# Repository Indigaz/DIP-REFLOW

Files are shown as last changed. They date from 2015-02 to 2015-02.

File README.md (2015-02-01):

# DIP-REFLOW
An all through-hole, Arduino powered, reflow oven controller.

Have you ever wondered why most toaster oven reflow controllers require a shield on a development board,
or the controller has a number of surface mounted components on the PCB?  I did too and I didn't want to
sacrifice a development board, that I frequently use and tear apart, into a long-term installation such
as a reflow controller.

This reflow controller is based on RocketScream's Arduino shield based reflow controller, however, this is
a fully hand solderable, all through-hole implementaion.  It makes use of a MAX31855 breakout board
available from Adafruit (http://www.adafruit.com/product/269) to read the K-type thermocouple.

The Arduino code has been pieced together from several sources to add the features and to get the 
functionality that I was looking for. 

**I still need to finish up a Bill-of-Materials list and cleanup the code somewhat.  Boards will be available on
OSHPark for a quick purchase or you can send off the .BRD file to your fab shop of choice.  I'll also look
at rendering a quality PDF file for those that might want to try and hand craft the PCB at home.  Note, this is
a two sided board.**

I will have this project also tracked at http://hackaday.io for more information such as assembly photos.

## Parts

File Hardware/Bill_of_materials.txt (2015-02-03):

DIP_REFLOW's initial Bill-of-materials:

Qty (1) ATMEGA328PDIP  (with or without Arduino bootloader.  ICSP worked into board.)
Qty (1) MAX31855 Breakout board (http://www.adafruit.com/product/269)
Qty (1) K-type thermocouple (Found on Adafruit, eBay or many other sites.)
Qty (1) 16x4 HD44780 Character LCD Display Module (Various sites)
Qty (1) 16 Mhz Crystal oscillator (Various sites)
Qty (1) 10k Ohm potentiometer (Various sites)
Qty (2) LED's (One RED and on GREEN) (Various sites)
Qty (3) Push button momentary switch (Various sites)
Qty (3) 2N3904 Transistor
Qty (2) 22pF Ceramic caps
Qty (3) .1uF Ceramic caps
Qty (3) 10k Ohm resistors
Qty (2) 330 Ohm resistors
Qty (4) Small 2 screw terminals
Qty (1) 3X2 ICSP header
Qty (1) 6 pin female header for MAX31855 breakout
Qty (1) 6 pin male or female header depending on your FTDI breakout
Qty (1) 7805 in TO220 size

This is just a quick draft to get information up and available.  I will later create a proper BOM
with part numbers and source location.

If anyone notices a problem, please alert me!  I'm pretty sure I've forgotten something.  Thanks!

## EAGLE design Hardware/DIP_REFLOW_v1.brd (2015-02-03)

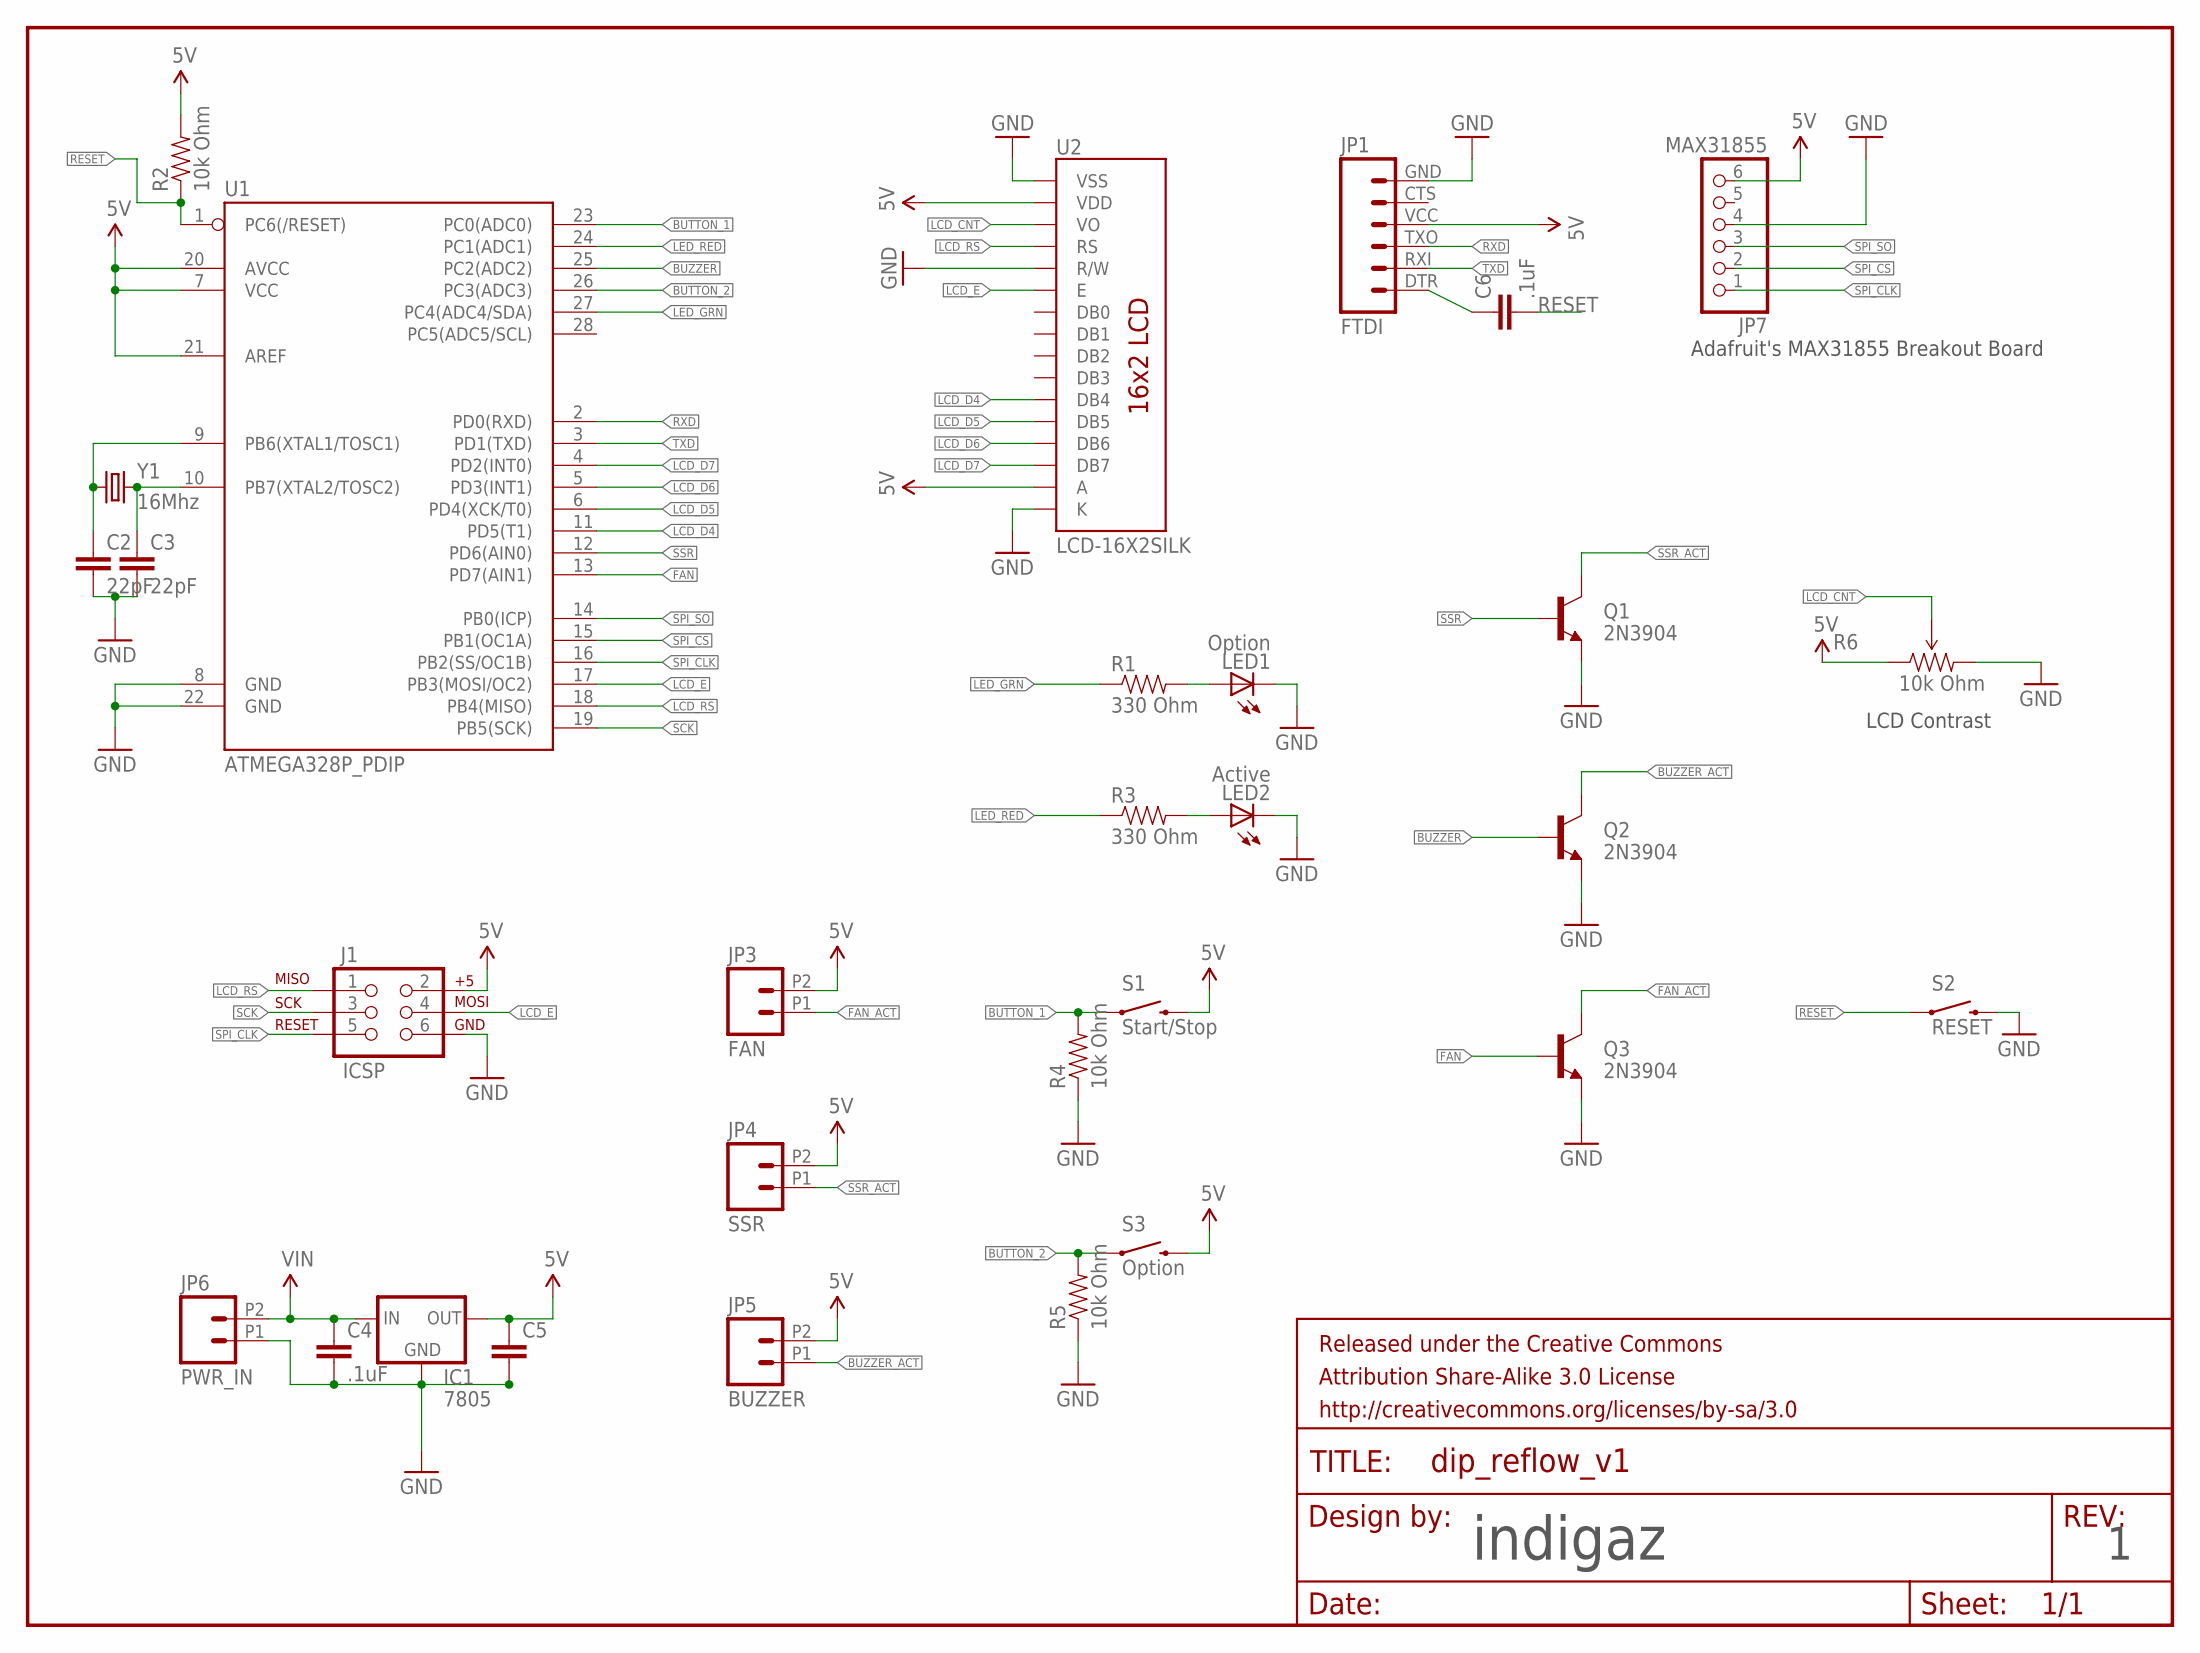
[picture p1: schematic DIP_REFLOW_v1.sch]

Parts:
C2, C3: 22pF; CAP-PTH-5MM
C4, C6: .1uF; CAP-PTH-5MM
C5: CAPPTH1; CAP-PTH-5MM
FRAME1: FRAME-LETTER; CREATIVE_COMMONS
IC1: 7805; TO-220-ALT
J1: ICSP; 2X3
JP1: FTDI; FTDI_BASIC
JP3: FAN; 1X02_2.54_SCREWTERM
JP4: SSR; 1X02_2.54_SCREWTERM
JP5: BUZZER; 1X02_2.54_SCREWTERM
JP6: PWR_IN; 1X02_2.54_SCREWTERM
JP7: MAX31855; 1X06
LED1: Option; LED5MM
LED2: Active; LED5MM
Q1, Q2, Q3: 2N3904; TO-92-AMMO
R1, R3: 330 Ohm; AXIAL-0.4
R2, R4, R5: 10k Ohm; AXIAL-0.4
R6: 10k Ohm; 3386U
S1: Start/Stop; TACTILE-PTH
S2: RESET; TACTILE-PTH
S3: Option; TACTILE-PTH
U1: ATMEGA328P_PDIP; DIL28-3
U2: LCD-16X2SILK; LCD-16X2
Y1: 16Mhz; HC49US

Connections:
5V: C5.1, IC1.OUT, J1.2, JP1.VCC (4), JP3.P2 (2), JP4.P2 (2), JP5.P2 (2), JP7.6, R2.P$2 (2), R6.1 (CCW), S1.3 (2), S3.3 (2), U1.7 (VCC), U1.20 (AVCC), U1.21 (AREF), U2.2 (VDD), U2.15 (A)
BUTTON_1: R4.P$2 (2), S1.1, U1.23 (PC0(ADC0))
BUTTON_2: R5.P$2 (2), S3.1, U1.26 (PC3(ADC3))
BUZZER: Q2.2 (B), U1.25 (PC2(ADC2))
BUZZER_ACT: JP5.P1 (1), Q2.3 (C)
FAN: Q3.2 (B), U1.13 (PD7(AIN1))
FAN_ACT: JP3.P1 (1), Q3.3 (C)
GND: C2.2, C3.2, C4.2, C5.2, IC1.GND, J1.6, JP1.GND (6), JP6.P1 (1), JP7.4, LED1.K (C), LED2.K (C), Q1.1 (E), Q2.1 (E), Q3.1 (E), R4.P$1 (1), R5.P$1 (1), R6.3 (CW), S2.3 (2), U1.8 (GND), U1.22 (GND), U2.1 (VSS), U2.5 (R/W), U2.16 (K)
LCD_CNT: R6.2 (WIPER), U2.3 (VO)
LCD_D4: U1.11 (PD5(T1)), U2.11 (DB4)
LCD_D5: U1.6 (PD4(XCK/T0)), U2.12 (DB5)
LCD_D6: U1.5 (PD3(INT1)), U2.13 (DB6)
LCD_D7: U1.4 (PD2(INT0)), U2.14 (DB7)
LCD_E: J1.4, U1.17 (PB3(MOSI/OC2)), U2.6 (E)
LCD_RS: J1.1, U1.18 (PB4(MISO)), U2.4 (RS)
LED_GRN: R1.P$1 (1), U1.27 (PC4(ADC4/SDA))
LED_RED: R3.P$1 (1), U1.24 (PC1(ADC1))
unnamed: C6.1, JP1.DTR (1)
unnamed: C2.1, U1.9 (PB6(XTAL1/TOSC1)), Y1.1
unnamed: LED1.A, R1.P$2 (2)
unnamed: C3.1, U1.10 (PB7(XTAL2/TOSC2)), Y1.2
unnamed: LED2.A, R3.P$2 (2)
RESET: C6.2, R2.P$1 (1), S2.1, U1.1 (PC6(/RESET))
RXD: JP1.TXO (3), U1.2 (PD0(RXD))
SCK: J1.3, U1.19 (PB5(SCK))
SPI_CLK: J1.5, JP7.1, U1.16 (PB2(SS/OC1B))
SPI_CS: JP7.2, U1.15 (PB1(OC1A))
SPI_SO: JP7.3, U1.14 (PB0(ICP))
SSR: Q1.2 (B), U1.12 (PD6(AIN0))
SSR_ACT: JP4.P1 (1), Q1.3 (C)
TXD: JP1.RXI (2), U1.3 (PD1(TXD))
VIN: C4.1, IC1.IN, JP6.P2 (2)

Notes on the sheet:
indigaz
Adafruit's MAX31855 Breakout Board
LCD Contrast

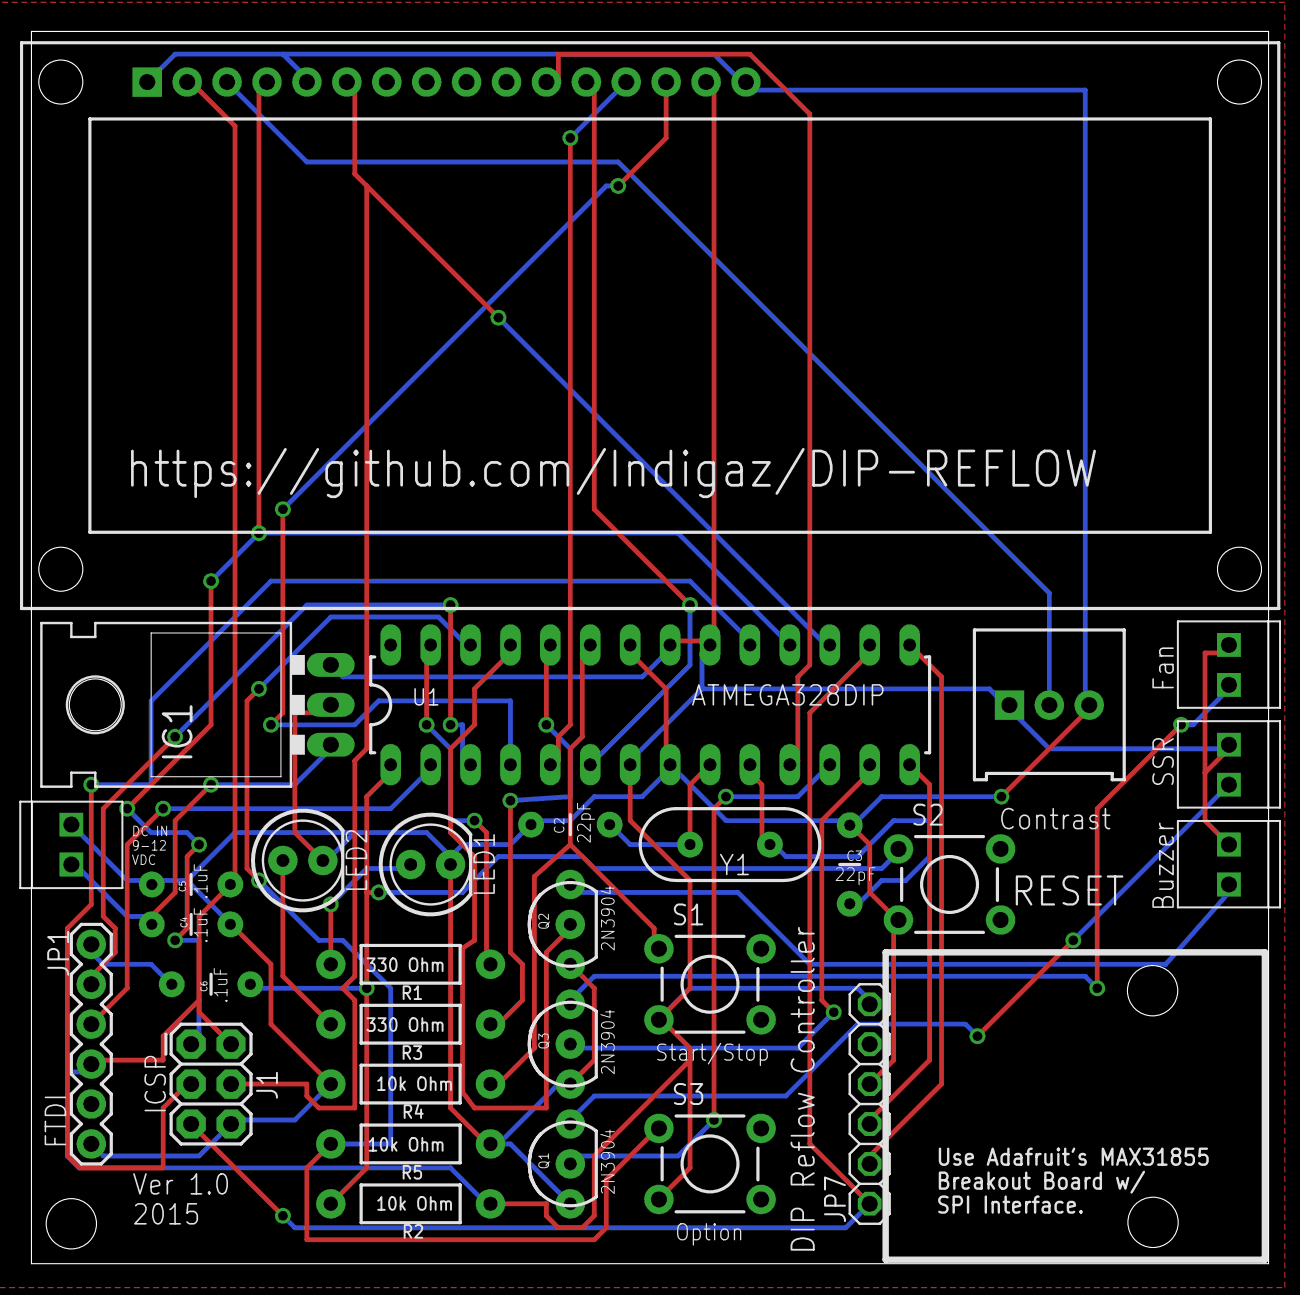
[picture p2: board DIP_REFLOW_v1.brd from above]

Board: 2 copper layers, 78.7 x 78.4 mm, 31 parts (0 on the bottom side), 32 nets.

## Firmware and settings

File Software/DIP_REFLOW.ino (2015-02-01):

/*******************************************************************************
 * Title: Reflow Oven Controller
 * Version: 1.20
 * Date: 2012-0225
 * Company: Rocket Scream Electronics
 * Website: www.rocketscream.com
 * 
 * ==============================================================================
 * Additional modifications: (2012) Scott Vitale (ksv_prj [at] gmx [dot] com
 * ==============================================================================
 * 
 * Revision  Description
 * ========  ===========
 * 1.20	     KSV - Added support for 2x16 "external display". 
 *            Added support for displaying real-time temperature slope
 *            Added support for remaining "soak time"
 *            Added support for elapsed time at "wet zone" temperature
 *            Changed "Profile Active" LED to be driven from FAN SSR. 
 * 1.10        Arduino IDE 1.0 compatible.
 * 1.00        Initial public release.
 ********************************************************************************
 * Brief
 * =====
 * This is an example firmware for our Arduino compatible reflow oven controller. 
 * The reflow curve used in this firmware is meant for lead-free profile 
 * (it's even easier for leaded process!). Please check our wiki 
 * (www.rocketscream.com/wiki) for more information on using this piece of code 
 * together with the reflow oven controller.
 *
 * Temperature (Degree Celcius)                 Magic Happens Here!
 * 245-|                                               x  x  
 *     |                                            x        x
 *     |                                         x              x
 *     |                                      x                    x
 * 200-|                                   x                          x
 *     |                              x    |                          |   x   
 *     |                         x         |                          |       x
 *     |                    x              |                          |
 * 150-|               x                   |                          |
 *     |             x |                   |                          |
 *     |           x   |                   |                          | 
 *     |         x     |                   |                          | 
 *     |       x       |                   |                          | 
 *     |     x         |                   |                          |
 *     |   x           |                   |                          |
 * 30 -| x             |                   |                          |
 *     |<  60 - 90 s  >|<    90 - 120 s   >|<       90 - 120 s       >|
 *     | Preheat Stage |   Soaking Stage   |       Reflow Stage       | Cool
 *  0  |_ _ _ _ _ _ _ _|_ _ _ _ _ _ _ _ _ _|_ _ _ _ _ _ _ _ _ _ _ _ _ _ _ _ _ _ 
 *                                                                Time (Seconds)
 *
 * This firmware owed very much on the works of other talented individuals as
 * follows:
 * ==========================================
 * Brett Beauregard (www.brettbeauregard.com)
 * ==========================================
 * Author of Arduino PID library. On top of providing industry standard PID 
 * implementation, he gave a lot of help in making this reflow oven controller 
 * possible using his awesome library.
 *
 * ==========================================
 * Limor Fried of Adafruit (www.adafruit.com)
 * ==========================================
 * Author of Arduino MAX31855 library. Adafruit has been the source of tonnes of
 * tutorials, examples, and libraries for everyone to learn.
 *
 * Disclaimer
 * ==========
 * Dealing with high voltage is a very dangerous act! Please make sure you know
 * what you are dealing with and have proper knowledge before hand. Your use of 
 * any information or materials on this reflow oven controller is entirely at 
 * your own risk, for which we shall not be liable. 
 *
 * Licences
 * ========
 * This reflow oven controller hardware and firmware are released under the 
 * Creative Commons Share Alike v3.0 license
 * http://creativecommons.org/licenses/by-sa/3.0/ 
 * You are free to take this piece of code, use it and modify it. 
 * All we ask is attribution including the supporting libraries used in this 
 * firmware. 
 *
 *******************************************************************************/
// ***** INCLUDES *****
#include <LiquidCrystal.h>
#include "Adafruit_MAX31855.h"
#include "PID_v1.h"
#include <SPI.h> 

#define TEST 0  // set to "1" to enable test code/constants
#define DEBUG 0 // set to "1" to enable debug via Serial

// ***** TYPE DEFINITIONS *****
typedef enum REFLOW_STATE{
  REFLOW_STATE_IDLE,
  REFLOW_STATE_PREHEAT,
  REFLOW_STATE_SOAK,
  REFLOW_STATE_REFLOW,
  REFLOW_STATE_COOL,
  REFLOW_STATE_COMPLETE,
  REFLOW_STATE_ERROR
} 
reflowState_t;

typedef enum REFLOW_STATUS{
  REFLOW_STATUS_OFF,
  REFLOW_STATUS_ON
} 
reflowStatus_t;

typedef enum DEBOUNCE_STATE{
  DEBOUNCE_STATE_IDLE,
  DEBOUNCE_STATE_CHECK,
  DEBOUNCE_STATE_RELEASE
} 
debounceState_t;

// ***** CONSTANTS *****
// set "1" if LCD has "degree" character, else "0" 
#define HAS_DEGREE 0

// set "1" if LCD has "delta" character, else "0" 
#define HAS_DELTA 0

#if !TEST
//#define TEMPERATURE_ROOM 40
#define TEMPERATURE_ROOM 50
#else
#define TEMPERATURE_ROOM 80
#endif

#define TEMPERATURE_SOAK_MIN 160
#define TEMPERATURE_SOAK_MAX 165

#define SOAK_TEMPERATURE_STEP 5
//#if !TEST
#define SOAK_MICRO_PERIOD 180000  // 240 seconds to soak
//#else
//#define SOAK_MICRO_PERIOD 300000  // 5 minutes to soak
//#endif

#define TEMPERATURE_REFLOW_MIN 180  // spec'd wet region start
#define TEMPERATURE_REFLOW_MAX 250

#if !TEST
#define TEMPERATURE_COOL_MIN 60
#else
#define TEMPERATURE_COOL_MIN 80
#endif

// soak-to-reflow beeper "on" duration in mS
#define BEEPDURATION_REFLOW 250
// reflow-to-cool beeper "on" duration in mS
#define BEEPDURATION_COOL 2000
// cool-to-complete beeper "on" duration in mS
#define BEEPDURATION_COMPLETE 3000 

#define DEBOUNCE_PERIOD_MIN 75
#define THERMOCOUPLE_DISCONNECTED 10000

#define SENSOR_SAMPLING_TIME 1000
#define PID_SAMPLE_TIME 1000

// Define PWM @ 100% window size in mS
// Note: 2000mS appears to be a crucial value
#if !TEST
#define PWMWINDOW 2000
#else
#define PWMWINDOW 2500
#endif

// ******************* PID PARAMETERS ******************* 
// ***** PRE-HEAT STAGE *****
#define PID_KP_PREHEAT 300
#define PID_KI_PREHEAT 0.05
#define PID_KD_PREHEAT 400

// ***** SOAKING STAGE *****
#define PID_KP_SOAK 300 // These work well!
#define PID_KI_SOAK 0.05
#define PID_KD_SOAK 250
//#define PID_KP_SOAK 200  // These work well!
//#define PID_KI_SOAK 0.025
//#define PID_KD_SOAK 25
//#define PID_KP_SOAK 27.28
//#define PID_KI_SOAK 0.34
//#define PID_KD_SOAK 542.59

// ***** REFLOW STAGE *****
#define PID_KP_REFLOW 300
#define PID_KI_REFLOW 0.05
#define PID_KD_REFLOW 350

// ***** LCD MESSAGES *****
const char* lcdMessagesReflowStatus[] = {
  "Ready",
  "Pre-heat",
  "Soak",
  "Reflow",
  "Cool",
  "Complete",
  "Error"
};

// ***** DEGREE SYMBOL FOR LCD *****
#if !HAS_DEGREE
unsigned char degree[8]  = {
  140,146,146,140,128,128,128,128};
unsigned char degree_char = 0; // custom char code "1"
#else
unsigned char degree_char = 0xDF;
#endif
// ***** DELTA SYMBOL FOR LCD *****
#if !HAS_DELTA
unsigned char delta[8] = {
  B00000,  B00100,  B01010,  B10001,  B10001,  B11111,  B00000,  B00000};
unsigned char delta_char = 1; // custom char code "1"
#else
unsigned char delta_char = 0xE8;
#endif

// ***** PIN ASSIGNMENT *****
const int button1 = A0;
const int button2 = A3; // Not used at the moment.
const int ssr = 6;
const int buzzer = A2;
const int lcdRs = 12;
const int lcdE = 11;
const int lcdD4 = 5;
const int lcdD5 = 4;
const int lcdD6 = 3;
const int lcdD7 = 2;
const int ledRed = A1;
const int thermocoupleCLK = 10;
const int thermocoupleCS = 9;
const int thermocoupleSO = 8;
const int ledGreen = A4; // Not used at the moment.

// ***** PID CONTROL VARIABLES *****
double setpoint;
double input;
double p_input;
double slope;
double output;
double kp = PID_KP_PREHEAT;
double ki = PID_KI_PREHEAT;
double kd = PID_KD_PREHEAT;
int windowSize;
unsigned long windowStartTime;
unsigned long nextCheck;
unsigned long nextRead;
unsigned long timerSoak;
unsigned long SoakStartTime;
unsigned long ReflowStartTime;
unsigned long ReflowDwellTime;
unsigned long buzzerPeriod;

// Reflow oven controller state machine state variable
reflowState_t reflowState;
// Reflow oven controller status
reflowStatus_t reflowStatus;
// Button debounce state machine state variable
debounceState_t debounceState;
// Button debounce timer
long lastDebounceTime;
// Button press status
boolean buttonPressStatus;
// Seconds timer
int timerSeconds;

// Specify PID control interface
PID reflowOvenPID(&input, &output, &setpoint, kp, ki, kd, DIRECT);
// Specify LCD interface
LiquidCrystal lcd(lcdRs, lcdE, lcdD4, lcdD5, lcdD6, lcdD7);
// Specify MAX31855 thermocouple interface
Adafruit_MAX31855 thermocouple(thermocoupleCLK, thermocoupleCS, thermocoupleSO);

void setup()
{
  // SSR pin initialization to ensure reflow oven is off
  digitalWrite(ssr, LOW);
  pinMode(ssr, OUTPUT);

  // Buzzer pin initialization to ensure annoying buzzer is off
  digitalWrite(buzzer, LOW);
  pinMode(buzzer, OUTPUT);

  // LED pins initialization and turn on upon start-up (active low)
  //  digitalWrite(ledRed, LOW);
  digitalWrite(ledRed, HIGH);
  digitalWrite(ledGreen, LOW);
  //pinMode(fan, OUTPUT);
  pinMode(ledRed, OUTPUT);
  pinMode(ledGreen, OUTPUT);
  // Push button pins initialization
  pinMode(button1, INPUT);
  pinMode(button2, INPUT);

  // Start-up splash
  digitalWrite(buzzer, HIGH);
  lcd.begin(16, 2);
#if !HAS_DEGREE
  lcd.createChar(0, degree);
#endif
#if !HAS_DELTA
  lcd.createChar(1, delta);
#endif
  lcd.clear();
  lcd.print("Through-Hole");
  lcd.setCursor(0, 1);
  lcd.print("Oven 1.2");
  digitalWrite(buzzer, LOW);
  delay(2500);
  lcd.clear();

  // Serial communication at 57600 bps
  Serial.begin(57600);

  // Turn off LED (active low)
  //  digitalWrite(ledRed, HIGH);
  digitalWrite(ledRed, LOW);
  digitalWrite(ledGreen, HIGH);

  // Set window size
  windowSize = PWMWINDOW;
  // Initialize time keeping variable
  nextCheck = millis();
  // Initialize thermocouple reading varible
  nextRead = millis();
}

void loop()
{
  // Current time
  unsigned long now;

  // Time to read thermocouple?
  if (millis() > nextRead)
  {
    // Read thermocouple next sampling period
    nextRead += SENSOR_SAMPLING_TIME;
    // Read current temperature
    p_input = input ;            //save previous reading
    input = thermocouple.readCelsius();
    slope = (input - p_input);  // calculate the slope

    // If thermocouple is not connected
    if (input == THERMOCOUPLE_DISCONNECTED)
    {
      // Illegal operation without thermocouple
      reflowState = REFLOW_STATE_ERROR;
      reflowStatus = REFLOW_STATUS_OFF;
    }
  }

  if (millis() > nextCheck)
  {
    // Check input in the next seconds
    nextCheck += 1000;
    // If reflow process is on going
    if (reflowStatus == REFLOW_STATUS_ON)
    {
      // Toggle red LED as system heart beat
      digitalWrite(ledRed, !(digitalRead(ledRed)));
      // Increase seconds timer for reflow curve analysis
      timerSeconds++;
      if ( !DEBUG )
      {
        // Send temperature and time stamp to serial 
        //        if (timerSeconds < 10) Serial.print(" ") ;
        //        if (timerSeconds < 100) Serial.print(" ");
        Serial.print(timerSeconds);
        Serial.print(" ");
        Serial.print(setpoint);
        Serial.print(" ");
        Serial.print(input);
        Serial.print(" ");
        Serial.print(slope);
        Serial.print(" ");
        Serial.println(output);
      }
      else
      {
        Serial.print("T: "); 
        if (timerSeconds < 10) Serial.print(" ") ;
        if (timerSeconds < 100) Serial.print(" ");
        Serial.print(timerSeconds);
        Serial.print(" ");
        Serial.print(lcdMessagesReflowStatus[reflowState]);
        Serial.print(" In:");
        Serial.print(int(input));
        Serial.print(" RST:");
        Serial.print(ReflowStartTime);
        Serial.print(" RDT:");
        Serial.print(ReflowDwellTime);
        Serial.println();
      }
    }
    else
    {
      // Turn off red LED
      //   digitalWrite(ledRed, HIGH);
      digitalWrite(ledRed, LOW);
    }

    // Clear LCD
    lcd.clear();
    // Print current system state
    lcd.print(lcdMessagesReflowStatus[reflowState]);
    // Move the cursor to the 2 line
    lcd.setCursor(0, 1);

    // If currently in error state
    if (reflowState == REFLOW_STATE_ERROR)
    {
      // No thermocouple wire connected
      lcd.print("No ThermoCouple!");
    }
    else
    {
      unsigned int temp;
      unsigned int minutes;
      unsigned int seconds ; 
      // Print current temperature on 1st line
      lcd.setCursor(9, 0);
      if (input < 10) lcd.print(" ") ;
      if (input < 100) lcd.print(" ") ;
      lcd.print(int(input)) ;
      lcd.print(".") ;
      lcd.print(int( ( input - int( input ) ) * 10) );
      lcd.write((uint8_t)degree_char);  // Print "degree" symbol
      lcd.print("C");

      // Print remaining time and slope on 2nd line
      lcd.setCursor(0, 1);
      if ( reflowState == REFLOW_STATE_SOAK ) {
        lcd.print("Rem:");
        temp = ( (SOAK_MICRO_PERIOD/1000) - ( timerSeconds - SoakStartTime ) );
        minutes = int(temp / 60 );
        seconds = int(temp % 60 );
        if (minutes < 10) lcd.print(" ") ;
        lcd.print(minutes);
        lcd.print(":");
        if (seconds < 10) lcd.print("0") ;
        lcd.print(seconds);
      }
      if (  (reflowState == REFLOW_STATE_REFLOW) || \
            (reflowState == REFLOW_STATE_COOL) ) {
        lcd.print("Wet:");
        if (ReflowStartTime == 0) { 
          temp = 0;  // display "0:00" till reflow min temp
        } 
        else {
          if (ReflowDwellTime == 0) {
            temp = ( timerSeconds - ReflowStartTime );
          } 
          else {
            temp = ReflowDwellTime;
          }
        }
        minutes = int(temp / 60 );
        seconds = int(temp % 60 );
        //        if (minutes < 10) lcd.print(" ") ;
        lcd.print(minutes);
        lcd.print(":");
        if (seconds < 10) lcd.print("0") ;
        lcd.print(seconds);
      }
      if (  ( reflowState == REFLOW_STATE_PREHEAT ) || \
            ( reflowState == REFLOW_STATE_REFLOW ) || \
            ( reflowState == REFLOW_STATE_COOL) ) {
        // Print slope
        lcd.setCursor(9, 1);
        lcd.write((uint8_t)delta_char);  // print "delta" symbol
        if ( slope<0 ) {
          lcd.print("-") ;  // "-" if negative slope
        } 
        else {    
          lcd.print("+") ;  // "+" if positive slope
        } 
        lcd.print(abs(int(slope))) ;
        lcd.print(".") ;
        lcd.print(abs( int( ( slope - int( slope ) ) * 10) ) ); // print slope
        lcd.write((uint8_t)degree_char);  // Print "degree" symbol
        lcd.print("C");
      } 
    }
  }

  // Reflow oven controller state machine
  switch (reflowState)
  {
  case REFLOW_STATE_IDLE:
    // If button is pressed to start reflow process
    if (buttonPressStatus)
    {
      // Ensure current temperature is comparable to room temperature
      // TO DO: To add indication that temperature is still high for
      // reflow process to start
      if (input <= TEMPERATURE_ROOM)
      {
        if ( !DEBUG )
        {
          // Send header for CSV file
          Serial.println("Time Setpoint Input Slope Output");
        }
        else {
          Serial.println("Debugging!");
        }
        // Intialize seconds timer for serial debug information
        timerSeconds = 0;
        // Initialize PID control window starting time
        windowStartTime = millis();
        // Ramp up to minimum soaking temperature
        setpoint = TEMPERATURE_SOAK_MIN;
        // Tell the PID to range between 0 and the full window size
        reflowOvenPID.SetOutputLimits(0, windowSize);
        reflowOvenPID.SetSampleTime(PID_SAMPLE_TIME);
        // Turn the PID on
        reflowOvenPID.SetMode(AUTOMATIC);
        // Proceed to preheat stage
        reflowState = REFLOW_STATE_PREHEAT;
      }
      else // Check to see if internal temp is too high to keep from thermal shocking board.
    {
      digitalWrite(buzzer, HIGH);
      lcd.clear();
      lcd.print("OvenTemp");
      lcd.setCursor(0, 1);
      lcd.print("Too High!");
      digitalWrite(buzzer, LOW);
      delay(2000);
      lcd.clear();
      digitalWrite(buzzer, HIGH);
      lcd.print("Aborting");
      lcd.setCursor(0, 1);
      lcd.print("Let Cool");
      digitalWrite(buzzer, LOW);
      delay(2000);
      }
    }
    break;

  case REFLOW_STATE_PREHEAT:
    reflowStatus = REFLOW_STATUS_ON;
    // If minimum soak temperature is achieve       
    if (input >= TEMPERATURE_SOAK_MIN)
    {
      // Chop soaking period into smaller sub-period
      timerSoak = millis() + SOAK_MICRO_PERIOD;
      // Set less agressive PID parameters for soaking ramp
      reflowOvenPID.SetTunings(PID_KP_SOAK, PID_KI_SOAK, PID_KD_SOAK);
      // Ramp up to first section of soaking temperature
      setpoint = TEMPERATURE_SOAK_MIN + SOAK_TEMPERATURE_STEP;   
      // Proceed to soaking state
      reflowState = REFLOW_STATE_SOAK; 
      SoakStartTime = timerSeconds ;  // set Soak Start Time 
    }
    break;

  case REFLOW_STATE_SOAK:     
    // If micro soak temperature is achieved       
    if (millis() > timerSoak)
    {
      timerSoak = millis() + SOAK_MICRO_PERIOD;
      // Increment micro setpoint
      setpoint += SOAK_TEMPERATURE_STEP;
      if (setpoint > TEMPERATURE_SOAK_MAX)
      {
        // Set agressive PID parameters for reflow ramp
        reflowOvenPID.SetTunings(PID_KP_REFLOW, PID_KI_REFLOW, PID_KD_REFLOW);
        // Ramp up to first section of soaking temperature
        setpoint = TEMPERATURE_REFLOW_MAX;   
        // Proceed to reflowing state
        reflowState = REFLOW_STATE_REFLOW; 
        ReflowStartTime = 0;
        buzzerPeriod = millis() + BEEPDURATION_REFLOW ;
        digitalWrite(buzzer, HIGH); //enable beeper
      }
    }
    break; 

  case REFLOW_STATE_REFLOW:
    if (millis() > buzzerPeriod) // turn off buzzer
    {
      digitalWrite(buzzer, LOW);
    }
    // We need to avoid hovering at peak temperature for too long
    // Crude method that works like a charm and safe for the components
    if ( (input >= TEMPERATURE_REFLOW_MIN) && (ReflowStartTime == 0 ) )
    { 
      ReflowStartTime = timerSeconds ;  // set Reflow Start Time 
    }
    if (input >= (TEMPERATURE_REFLOW_MAX - 5))
    {
      // Set PID parameters for cooling ramp
      reflowOvenPID.SetTunings(PID_KP_REFLOW, PID_KI_REFLOW, PID_KD_REFLOW);
      // Ramp down to minimum cooling temperature
      setpoint = TEMPERATURE_COOL_MIN;   
      // Proceed to cooling state
      reflowState = REFLOW_STATE_COOL; 
      buzzerPeriod = millis() + BEEPDURATION_COOL;
      digitalWrite(buzzer, HIGH);
    }
    break;   

  case REFLOW_STATE_COOL:
    if (millis() > buzzerPeriod) // turn off buzzer
    {
      digitalWrite(buzzer, LOW);
    }
    // Since we're cooling off, let's keep track of the "Wetting" time 
    if ( (ReflowDwellTime == 0) && (input <= TEMPERATURE_REFLOW_MIN) ) {
      ReflowDwellTime = ( timerSeconds - ReflowStartTime );
    } 
    // If minimum cool temperature is achieve       
    if (input <= TEMPERATURE_COOL_MIN)
    {
      // Retrieve current time for buzzer usage
      buzzerPeriod = millis() + BEEPDURATION_COMPLETE;
      // Turn on buzzer and green LED to indicate completion
      digitalWrite(ledGreen, LOW);
      digitalWrite(buzzer, HIGH);
      // Turn off reflow process
      reflowStatus = REFLOW_STATUS_OFF;                
      // Proceed to reflow Completion state
      reflowState = REFLOW_STATE_COMPLETE; 
    }         
    break;    

  case REFLOW_STATE_COMPLETE:
    if (millis() > buzzerPeriod)
    {
      // Turn off buzzer and green LED
      digitalWrite(buzzer, LOW);
      digitalWrite(ledGreen, HIGH);
      // Reflow process ended
      reflowState = REFLOW_STATE_IDLE; 
    }
    break;

  case REFLOW_STATE_ERROR:
    // If thermocouple is still not connected
    if (input == THERMOCOUPLE_DISCONNECTED)
    {
      // Wait until thermocouple wire is connected
      reflowState = REFLOW_STATE_ERROR; 
    }
    else
    {
      // Clear to perform reflow process
      reflowState = REFLOW_STATE_IDLE; 
    }
    break;    
  }    

  // If button is pressed
  if (buttonPressStatus == true)
  {
    // If currently reflow process is on going
    if (reflowStatus == REFLOW_STATUS_ON)
    {
      // Button press is for cancelling
      // Turn off reflow process
      reflowStatus = REFLOW_STATUS_OFF;
      // Reinitialize state machine
      reflowState = REFLOW_STATE_IDLE;
    }
  } 

  // Simple button debounce state machine (for button #1 only)
  // TO DO: To be replaced with interrupt version in next revision
  switch (debounceState)
  {
  case DEBOUNCE_STATE_IDLE:
    // No valid button press
    buttonPressStatus = false;
    // If button #1 is pressed
    if (digitalRead(button1) == LOW)
    {
      // Intialize debounce counter
      lastDebounceTime = millis();
      // Proceed to check validity of button press
      debounceState = DEBOUNCE_STATE_CHECK;
    }
    break;

  case DEBOUNCE_STATE_CHECK:
    // If button #1 is still pressed
    if (digitalRead(button1) == LOW)
    {
      // If minimum debounce period is completed
      if ((millis() - lastDebounceTime) > DEBOUNCE_PERIOD_MIN)
      {
        // Proceed to wait for button release
        debounceState = DEBOUNCE_STATE_RELEASE;
      }
    }
    // False trigger
    else
    {
      // Reinitialize button debounce state machine
      debounceState = DEBOUNCE_STATE_IDLE; 
    }
    break;
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

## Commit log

2015-02-01 Hardware files
    Uploading of DIP-REFLOW hardware files created in Eagle 6.4.
    [DIP_REFLOW.brd, DIP_REFLOW.sch]
2015-02-01 Software files
    The Arduino code to run the reflow controller.
2015-02-01 Update to .BRD file.
    [DIP_REFLOW_v1.brd, DIP_REFLOW_v1.sch]
2015-02-03 Updates and Fixes
    [DIP_REFLOW_v1.brd, DIP_REFLOW_v1.sch]
2015-02-03 :information_source: BOM added!

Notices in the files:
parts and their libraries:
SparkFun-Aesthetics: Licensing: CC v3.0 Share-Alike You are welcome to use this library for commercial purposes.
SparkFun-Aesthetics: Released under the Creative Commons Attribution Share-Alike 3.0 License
